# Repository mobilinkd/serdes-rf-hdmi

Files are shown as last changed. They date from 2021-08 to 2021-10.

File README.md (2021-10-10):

# serdes-rf-hdmi

HDMI test fixture for TMDS to single-ended SMA for RF testing.

This board is designed to test RF input and output using TMDS signals from the
Pynq-Z2 board's HDMI port.  It capacitively couples the clock signal for use
as an NCO (this is used in a single-ended output/input mode).  And it provides
two identical differentially-coupled signals for either RF input or RF output.

The RF signals are filtered by a 4th order Chebyshev bandpass filter.  The
RF is coupled to the TMDS pair via a center-tapped 1:1 RF transformer.  The
center tap is connected to ground via a 50 Ohm resistor.

The filter is designed for the 2m amateur radio band, but can easily be
adapted to other bands of interest.  It is important to have at a minimum
a low-pass filter with the 2λ at down least -40dB to prevent aliasing.

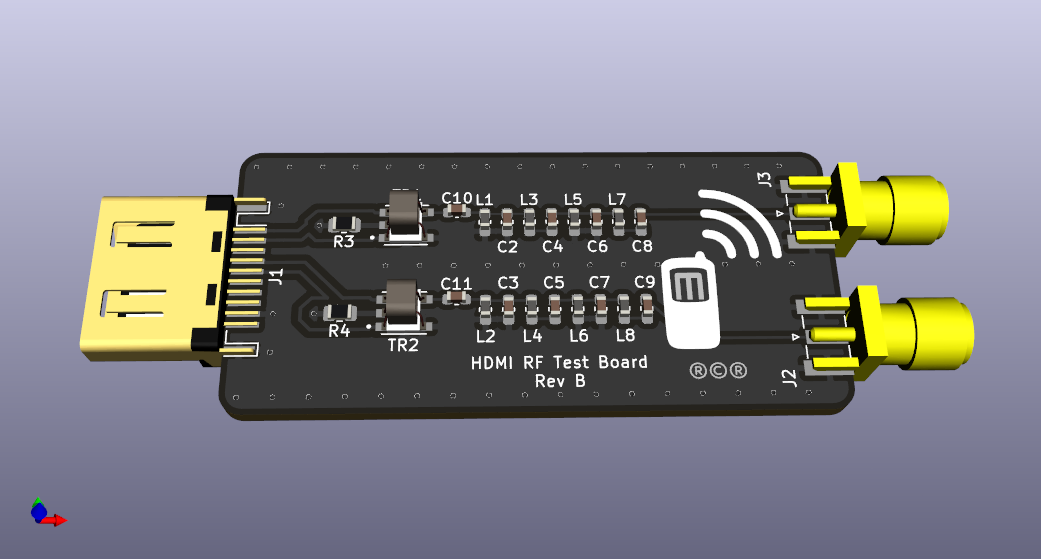
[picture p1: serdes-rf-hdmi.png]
PCB Render


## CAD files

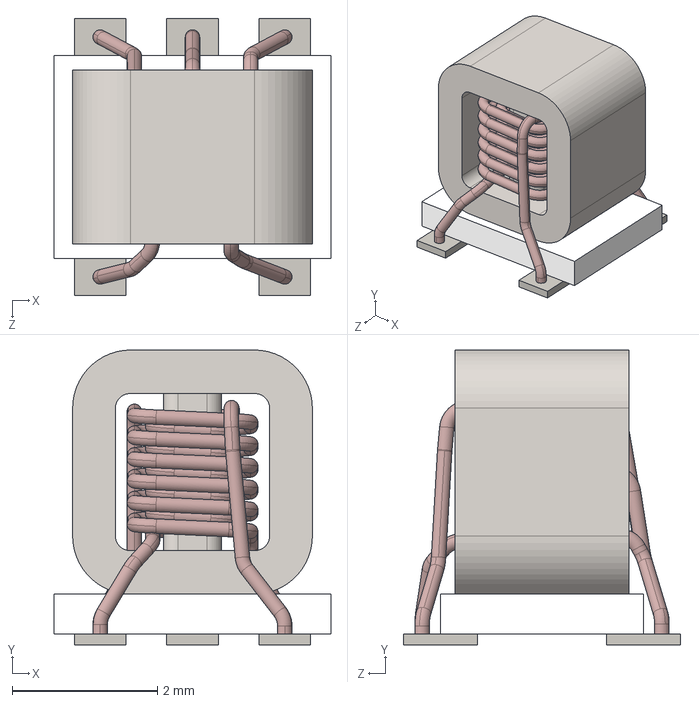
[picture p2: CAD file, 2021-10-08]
models/User Library-TC1-1T+.step
3.81 x 4.06 x 3.81 mm

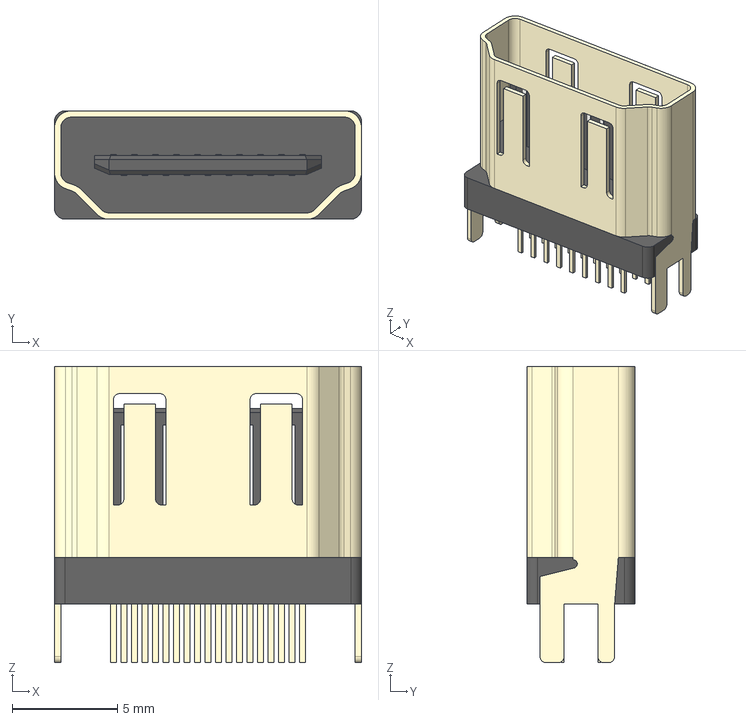
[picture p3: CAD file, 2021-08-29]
models/HDMI_vertical.stp
14.6 x 5.15 x 14.1 mm

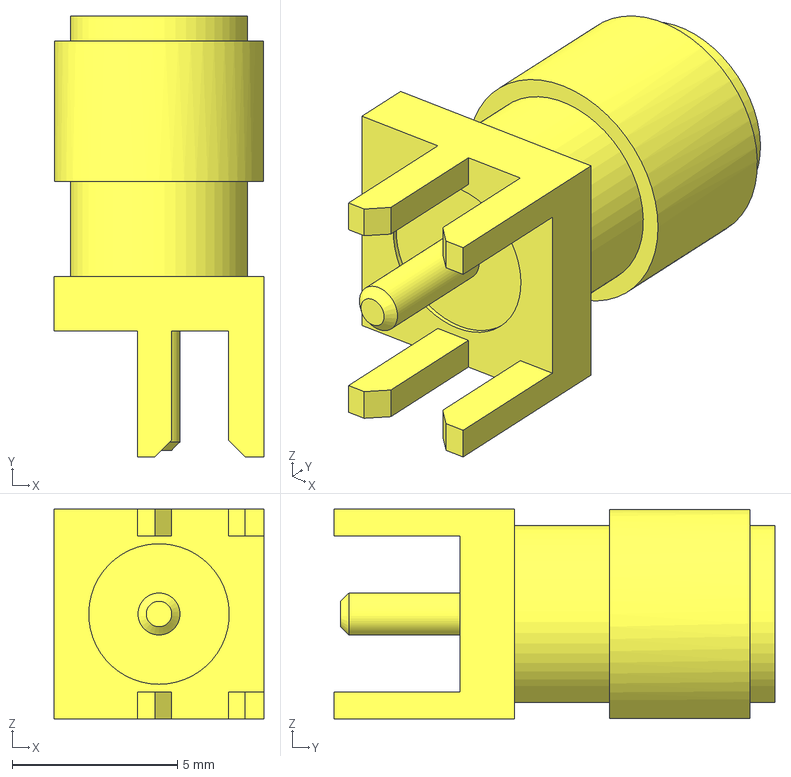
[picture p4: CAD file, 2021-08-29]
models/SMA-J-P-H-ST-EM1.stp
6.35 x 13.3 x 6.35 mm

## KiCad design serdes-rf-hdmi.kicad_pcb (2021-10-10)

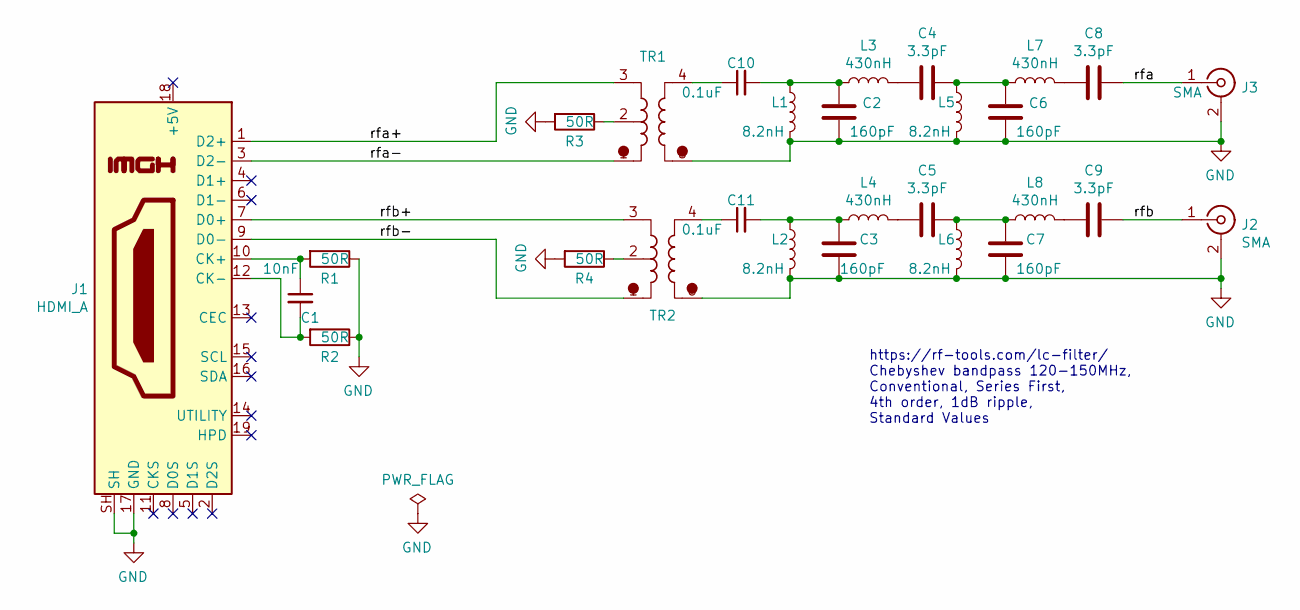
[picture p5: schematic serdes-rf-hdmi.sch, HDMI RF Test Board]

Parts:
C1: 10nF; C_0603_1608Metric
C2, C3, C6, C7: 160pF; C_0603_1608Metric_Pad1.08x0.95mm_HandSolder
C4, C5, C8, C9: 3.3pF; C_0603_1608Metric_Pad1.08x0.95mm_HandSolder
C10, C11: 0.1uF; C_0603_1608Metric
J1: HDMI_A; HDMI_A_Contact_Technology_HDMI-19APL2_Horizontal
J2, J3: SMA; SMA_Samtec_SMA-J-P-X-ST-EM1_EdgeMount
L1, L2, L5, L6: 8.2nH; L_0603_1608Metric_Pad1.05x0.95mm_HandSolder
L3, L4, L7, L8: 430nH; L_0603_1608Metric_Pad1.05x0.95mm_HandSolder
R1, R2, R3, R4: 50R; R_0805_2012Metric
TR1, TR2: TC1-1TX+; XFMR_TC1-1-13M+

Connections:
/rfa: C8.1, J3.1 (In)
/rfa+: J1.1 (D2+), TR1.3
/rfa-: J1.3 (D2-), TR1.1
/rfb: C9.1, J2.1 (In)
/rfb+: J1.7 (D0+), TR2.3
/rfb-: J1.9 (D0-), TR2.1
GND: C2.2, C3.2, C6.2, C7.2, J1.17 (GND), J1.SH, J2.2 (Ext), J3.2 (Ext), L1.2, L2.2, L5.2, L6.2, R1.1, R2.1, R3.2, R4.2, TR1.6, TR2.6
unnamed: C1.1, J1.10 (CK+), R1.2
unnamed: C1.2, J1.12 (CK-), R2.2
unnamed: C4.1, C6.1, L5.1, L7.1
unnamed: C4.2, L3.2
unnamed: C5.1, C7.1, L6.1, L8.1
unnamed: C5.2, L4.2
unnamed: C8.2, L7.2
unnamed: C9.2, L8.2
unnamed: C10.1, TR1.4
unnamed: C2.1, C10.2, L1.1, L3.1
unnamed: C11.1, TR2.4
unnamed: C3.1, C11.2, L2.1, L4.1
unnamed: R3.1, TR1.2
unnamed: R4.1, TR2.2

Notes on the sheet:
https://rf-tools.com/lc-filter/ Chebyshev bandpass 120-150MHz, Conventional, Series First, 4th order, 1dB ripple, Standard Values

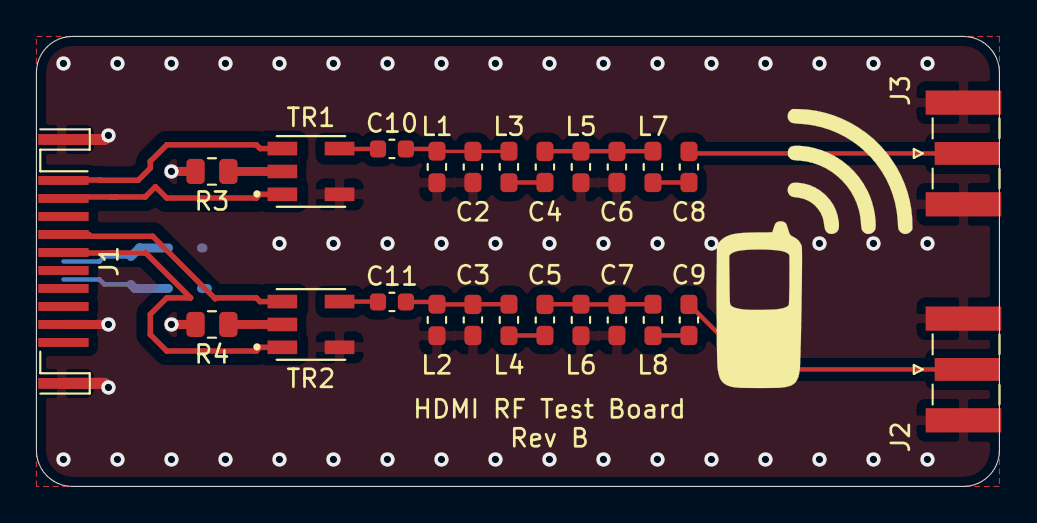
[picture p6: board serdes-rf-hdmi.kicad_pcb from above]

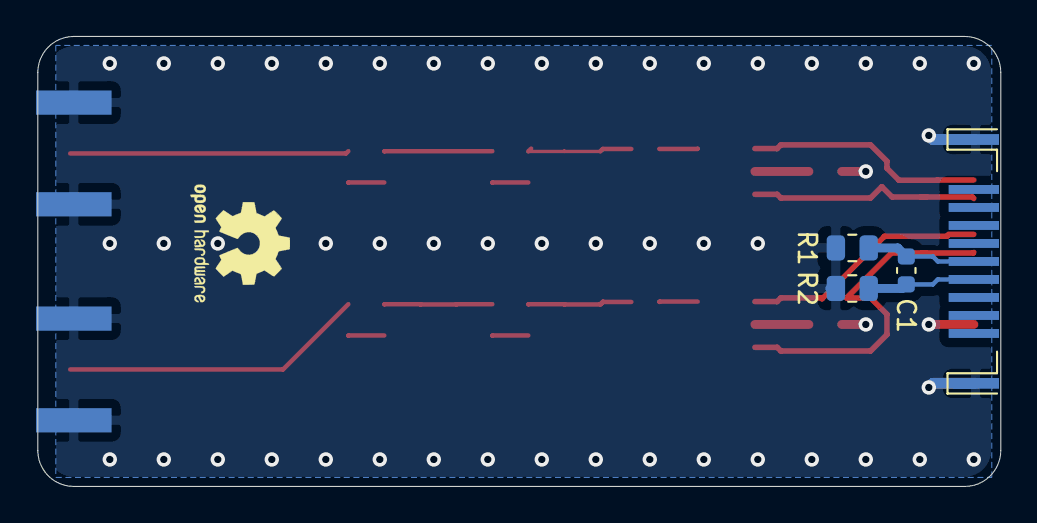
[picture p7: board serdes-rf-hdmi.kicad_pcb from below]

Board: 4 copper layers, 53.5 x 25.0 mm, 29 parts (3 on the bottom side), 21 nets.

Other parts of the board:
G1: LOGO; Mobilinkd_Logo

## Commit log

2021-08-29 Initial commit.
    [HDMI_vertical.stp, SMA-J-P-H-ST-EM1.stp, serdes-rf-hdmi.kicad_pcb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]
2021-08-30 Add Gerbers and update README.
    [serdes-rf-hdmi-B_Cu.gbr, serdes-rf-hdmi-B_Mask.gbr, serdes-rf-hdmi-B_Paste.gbr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]
2021-10-07 Start of rev B design.
    [serdes-rf-hdmi.kicad_pcb, serdes-rf-hdmi.sch]
2021-10-08 Rev B complete
    [User Library-TC1-1T+.step, serdes-rf-hdmi.kicad_pcb, serdes-rf-hdmi.sch]
2021-10-08 Update one track and generate Gerbers.
    [serdes-rf-hdmi-B_Cu.gbr, serdes-rf-hdmi-B_Mask.gbr, serdes-rf-hdmi-B_Paste.gbr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]
2021-10-10 Fix bandpass filter and add coupling caps. Update image and README.
    [serdes-rf-hdmi-B_Cu.gbr, serdes-rf-hdmi-B_Mask.gbr, serdes-rf-hdmi-B_Paste.gbr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]
2021-10-10 Trivial changes to layout.
    [serdes-rf-hdmi-B_Cu.gbr, serdes-rf-hdmi-B_Mask.gbr, serdes-rf-hdmi-B_Paste.gbr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]

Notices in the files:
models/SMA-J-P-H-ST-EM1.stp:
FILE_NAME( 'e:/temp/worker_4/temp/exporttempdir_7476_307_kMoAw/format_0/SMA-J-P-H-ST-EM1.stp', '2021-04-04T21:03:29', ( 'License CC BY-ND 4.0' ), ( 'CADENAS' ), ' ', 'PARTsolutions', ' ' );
